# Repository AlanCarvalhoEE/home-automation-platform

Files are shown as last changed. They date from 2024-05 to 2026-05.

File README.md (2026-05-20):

# Home Automation Platform (HAP)

A modular, self-hosted home automation platform focused on reliability, local control, and secure remote access.

The system is designed around a Raspberry Pi server that centralizes application logic and device state, ESP8266-based IoT modules for field control, and a mobile
application as the primary user interface. Communication between components is event-driven and optimized for embedded and low-latency environments.

---

## System Architecture

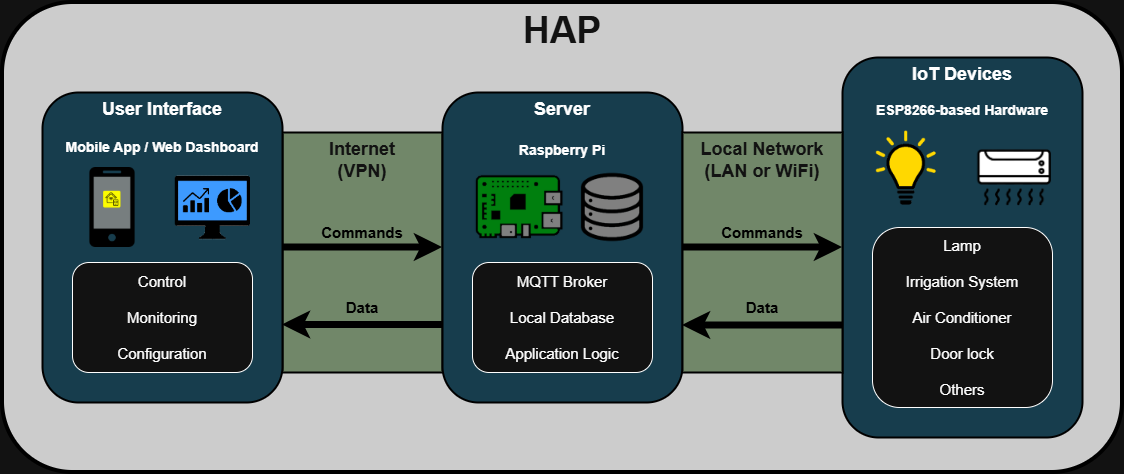
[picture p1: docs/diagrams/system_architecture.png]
System Architecture


The platform follows a layered architecture:

- **User Interface Layer**: Mobile and web-based interfaces for monitoring and
  control.
- **Application Layer**: Centralized logic running on a Raspberry Pi server.
- **Device Layer**: Custom ESP8266-based hardware modules controlling actuators
  and sensors.

Remote access is secured using a VPN, allowing the system to remain fully functional without relying on external cloud services.

---

## Components Overview

### Mobile App / Web Interface
- Provides real-time monitoring and control of devices
- Sends user commands to the server
- Displays device states and sensor data

### Server (Raspberry Pi)
- Central application logic
- Device state management
- Local database storage
- MQTT-based device communication
- REST API for configuration and user interfaces

### IoT Devices (ESP8266)
- Custom-designed hardware modules
- Event-driven communication using MQTT
- Designed as lightweight, replaceable nodes
- Examples:
  - On/Off relay modules
  - Sensor modules
  - Air conditioner control modules

---

## Repository Structure

```
hap/
├── docs/       # Documentation, diagrams, images
├── firmware/   # ESP8266 firmware for IoT modules
├── hardware/   # PCB designs, schematics, manufacturing files
├── mobile/     # Android application
├── server/     # Core server logic and services
└── README.md
```

---

## Technology Stack

### Embedded & Hardware
- ESP8266
- C / Arduino framework
- Custom PCB design

### Server
- Raspberry Pi
- Python
- MQTT
- SQLite
- TCP/IP networking

### Mobile
- Android (Java)
- Local and remote control support

### Communication & Security
- MQTT for device communication
- REST API for configuration and UI interaction
- VPN-based secure remote access
- Local-first architecture (no cloud dependency)

---

## Communication Model

- Devices publish state changes and sensor data via MQTT
- The server processes events and applies application logic
- Commands are sent back to devices via MQTT topics
- The mobile app interacts with the server through secure API calls

---

## System Setup Steps

- Install a lightweight Raspberry Pi OS:
  - Raspberry Pi OS Lite (recommended)
  - Enable SSH during installation
  - Configure a static local IP address

- Update the system:
```
sudo apt update
sudo apt upgrade -y
```

- Install and configure GIT:
```
sudo apt install git -y
```

- Clone the repository:
```
git clone https://github.com/AlanCarvalhoEE/hap.git
```

- Enter project folder:
```
cd hap
```

- Edit your credentials:
```
cp server/scripts/credentials_example.py server/scripts/credentials.py
nano server/scripts/credentials.py
```

- Run setup.sh:
```
cd setup
chmod +x setup.sh
./setup.sh
```
  - The script will install all the needed packages, dependencies and services.

- Configure Mosquitto:
```
sudo nano /etc/mosquitto/mosquitto.conf
```
  - Include to the end of the file:
  ```
  listener 1883
  allow_anonymous true
  ```

- Restart Mosquitto:
```
sudo systemctl restart mosquitto
```

- Connect to your ZeroTier network (must be previously created on web browser):
```
sudo zerotier-cli join <network_id>
```
  - After joining, the device must be allowed on the ZeroTier network dashboard.

- Reboot the Raspberry Pi:
```
sudo reboot now
```

---

## Current Status

- Core server architecture implemented
- Custom IoT ON-OFF module developed and tested
- Core Android application implemented
- Secure remote access functional

---

## Roadmap

Planned improvements:

- New custom IoT modules development
- Formal MQTT topic and message schema documentation
- Device auto-discovery and provisioning
- Improved fault tolerance and reconnection logic
- Automated testing for server-side logic
- Expanded mobile app features and UI refinement

---

## License

This project is currently intended for personal and educational use.
Licensing details may be defined in the future.

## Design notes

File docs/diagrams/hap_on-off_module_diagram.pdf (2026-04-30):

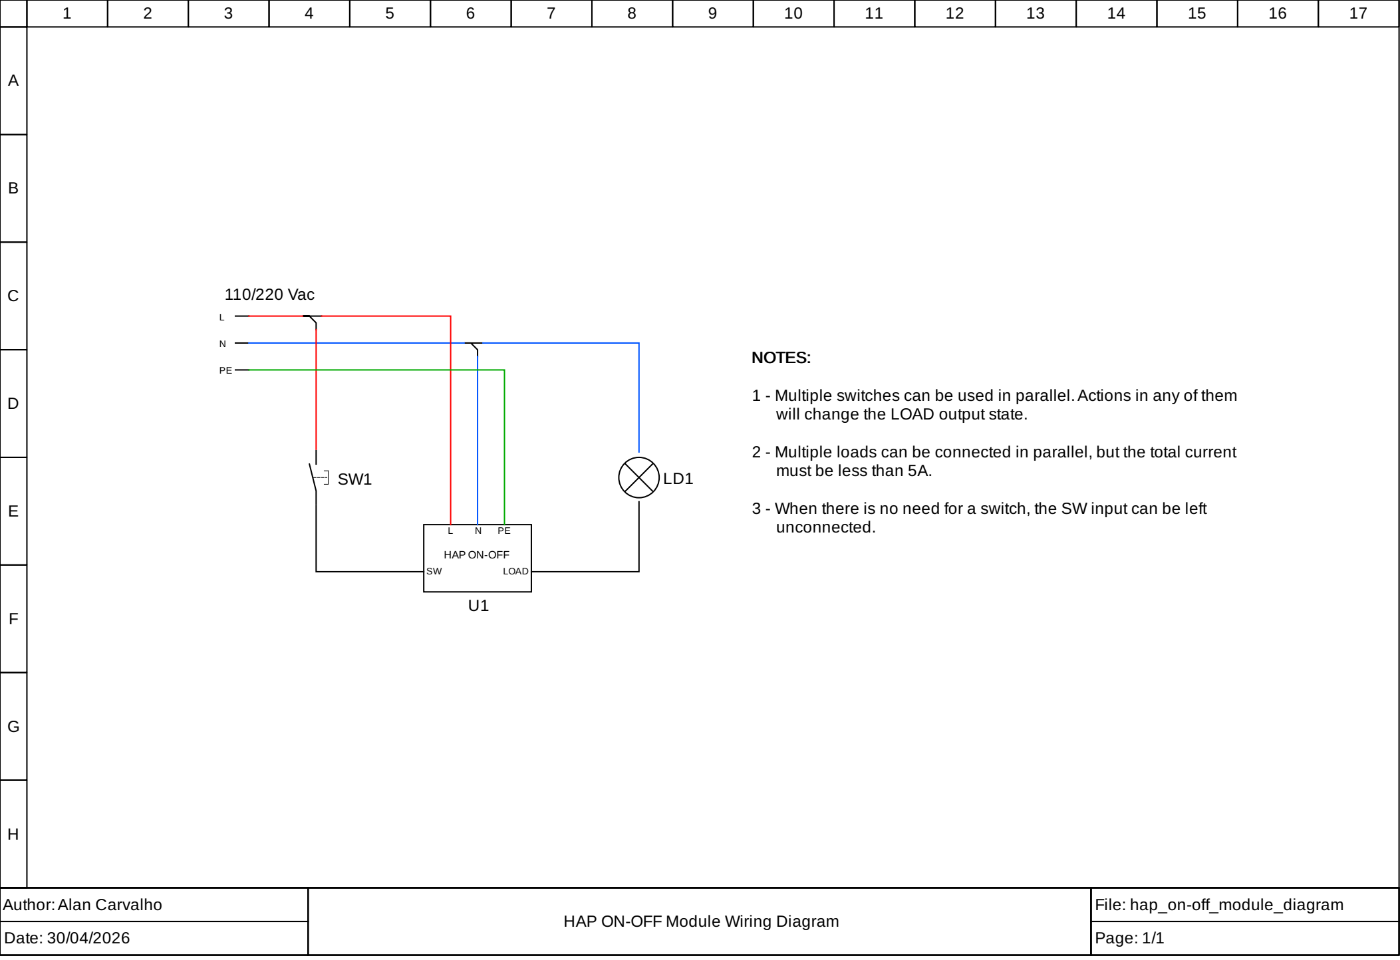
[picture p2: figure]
Author:Alan Carvalho; HAP ON-OFF Module Wiring Diagram; File: hap_on-off_module_diagram; Date: 30/04/2026; Page: 1/1; 110/220 Vac; NOTES:; will change the LOAD output state.; must be less than 5A.; unconnected.; LOAD; HAP ON-OFF

1 - Multiple switches can be used in parallel.Actions in any of them

2 - Multiple loads can be connected in parallel, but the total current

3 - When there is no need for a switch, the SW input can be left

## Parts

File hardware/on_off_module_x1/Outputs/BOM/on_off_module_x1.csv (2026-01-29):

Quantity | Value | Footprint | Designators
C1 | 0.1uF - 275V | CAP_THT_CERAMIC_X2_18x6x15 | 1
C2 | 100uF - 16V | CAP_SMD_ELEC_6.3x7.7 | 1
C3 | 10uF - 16V | CAP_SMD_TANTALUM_CASE-A | 1
C4 | 10uF - 6.3V | CAP_SMD_TANTALUM_CASE-A | 1
C5 | 0.1uF - 6.3V | CAP_SMD_CERAMIC_0603 | 1
C6 | 47nF - 350V | CAP_THT_CERAMIC_X2_13x5x11_P10 | 1
C7 | 100nF - 6 | 3V | CAP_SMD_CERAMIC_0603 | 1
D1 | LED | LED_SMD_0603 | 1
D2 | S1A | DIODE_SMD_SMA | 1
F1 | 0 | 25A - 250V | FUSEHOLDER_THT_5x20_CLIP | 1
J1 | CONN_TERMINAL-BLOCK_5P_P5.08 | CONN_TERMINAL-BLOCK_5P_P5.08 | 1
J2 | Conn_01x06_Socket | CONN_SOCKET-HEADER_1x06_V | 1
J3 | Conn_01x03_Socket | CONN_PIN-HEADER_1x03_V | 1
K1 | 12V 5A | RELAY_SPDT_FINDER_36.11 | 1
L1 | 600R | BEAD_SMD_1206 | 1
PS1 | HLK-PM12 - 3W | HILINK_HLK-PMxx | 1
Q1 | 2N7002H | SOT-23 | 1
R10 | R11 | 33k - 5% - 1/4W | RES_SMD_1206 | 2
R1 | R2 | R3 | R6 | R12 | 10k - 5% - 1/10W | RES_SMD_0603 | 5
R4 | 2k2 - 5% - 1/10W | RES_SMD_0603 | 1
R5 | 390R - 5% - 1/10W | RES_SMD_0603 | 1
R7 | 33k - 5% - 1/10W | RES_SMD_0603 | 1
R8 | 10k | LDR_5_V | 1
R9 | 470k - 5% - 1/4W | RES_SMD_1206 | 1
U1 | AMS1117-3.3 - 3.3W | SOT-223-3_TAB2 | 1
U2 | ESP-12E | MOD_ESP-12E | 1
U3 | PC817 | SMDIP-4_7.62 | 1
U4 | H11AA1 | SMDIP-6_7.62 | 1

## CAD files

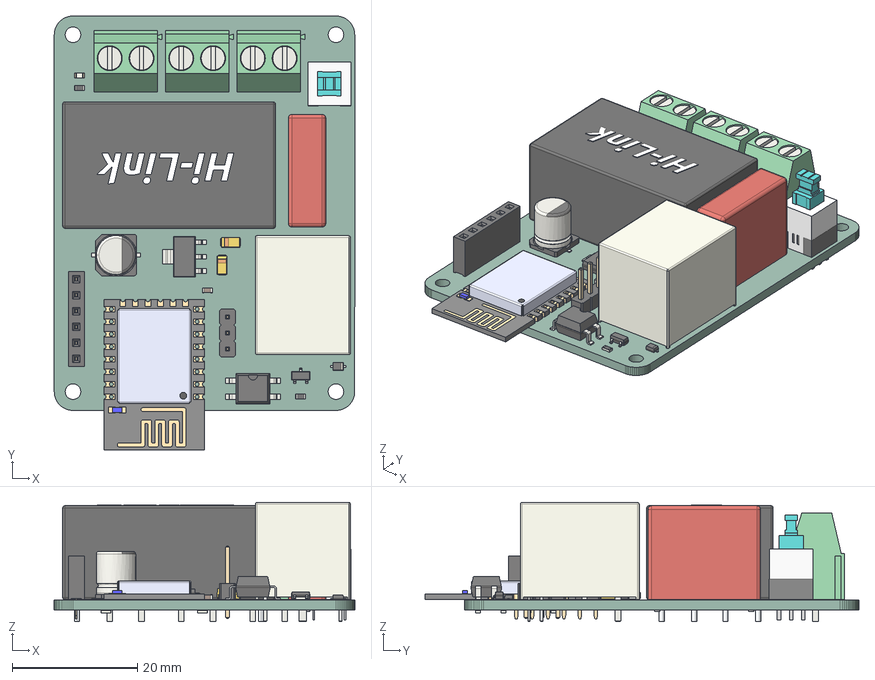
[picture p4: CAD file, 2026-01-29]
hardware/on_off_module_x1/ON-OFF Module X1 PCB.step
48.0 x 69.3 x 19.0 mm
on_off_module_x1 PCB

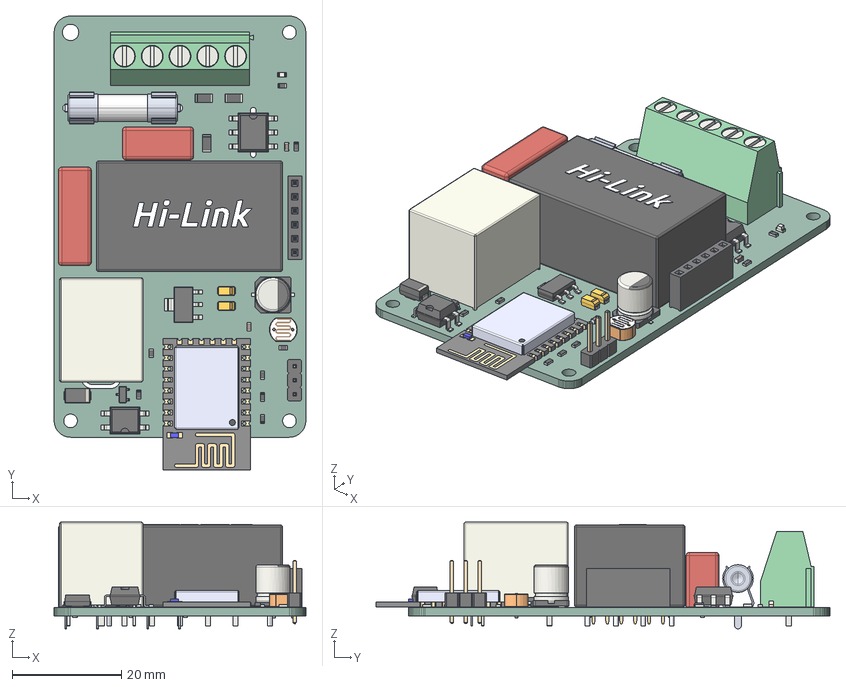
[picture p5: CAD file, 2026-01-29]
hardware/on_off_module_x1/Outputs/3D/on_off_module_x1.step
46.0 x 83.0 x 19.5 mm
on_off_module_x1 PCB

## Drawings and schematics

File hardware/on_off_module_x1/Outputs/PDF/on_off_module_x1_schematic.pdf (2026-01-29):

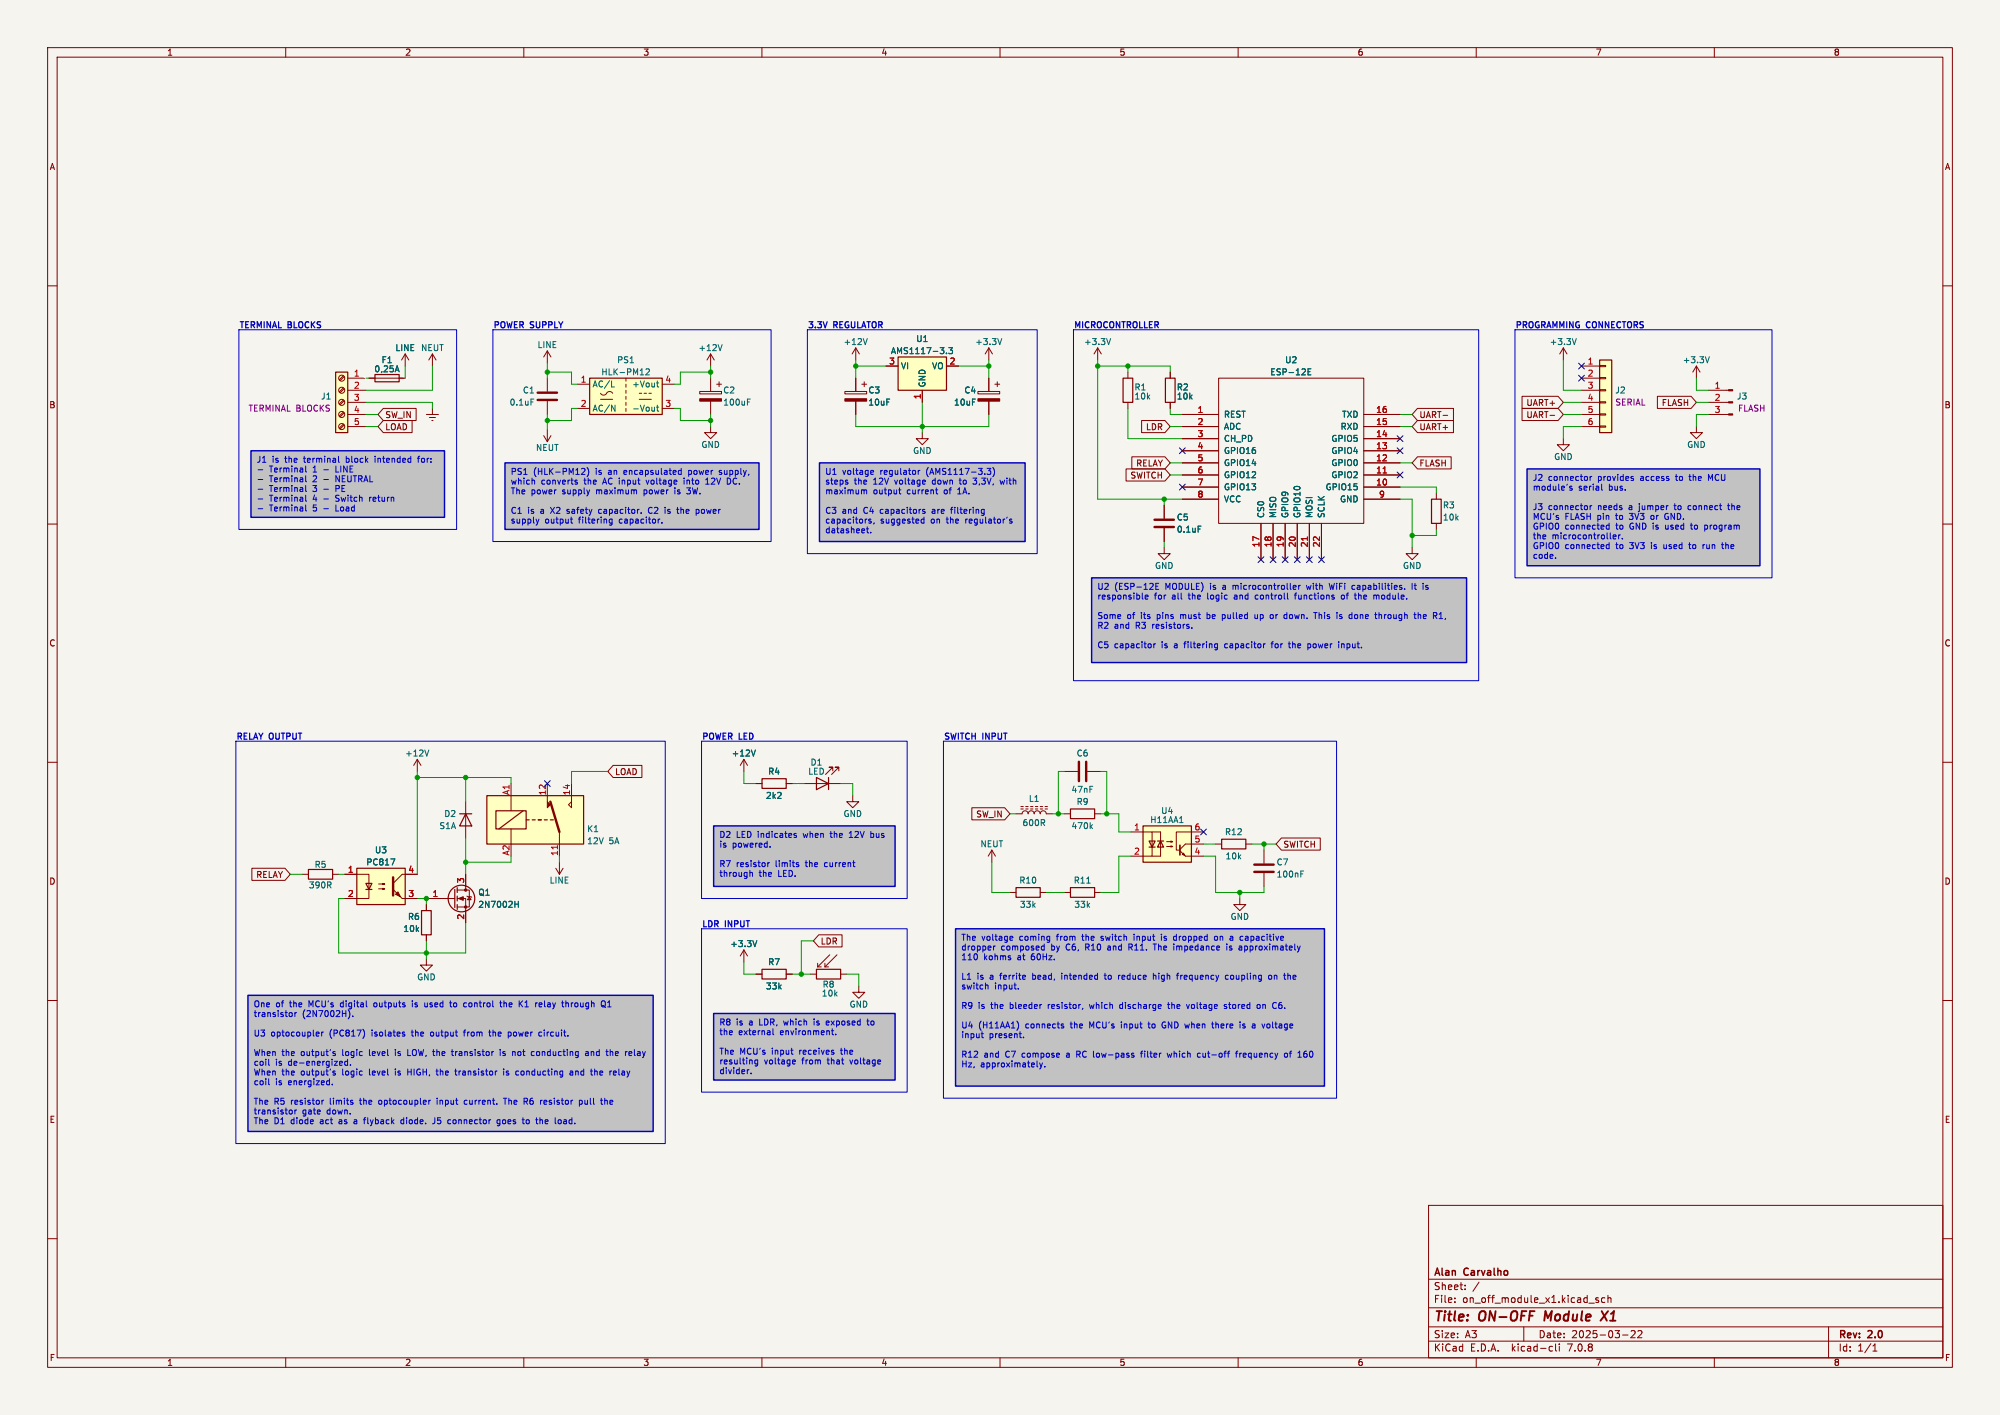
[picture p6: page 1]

File: on_off_module_x1.kicad_sch Sheet: / Alan Carvalho GND

Id: 1/1 Title: ON-OFF Module X1

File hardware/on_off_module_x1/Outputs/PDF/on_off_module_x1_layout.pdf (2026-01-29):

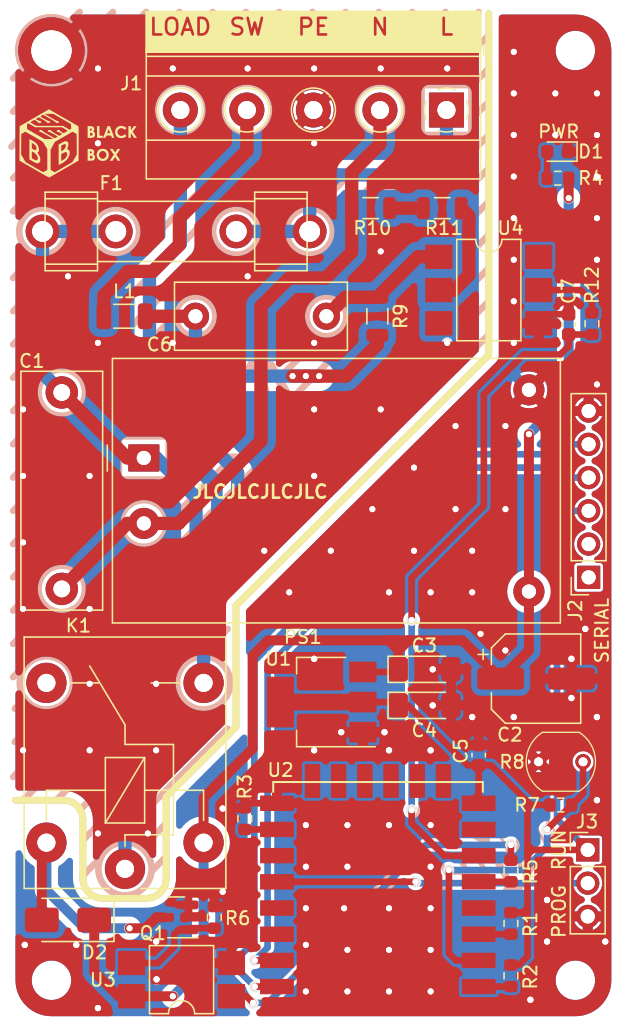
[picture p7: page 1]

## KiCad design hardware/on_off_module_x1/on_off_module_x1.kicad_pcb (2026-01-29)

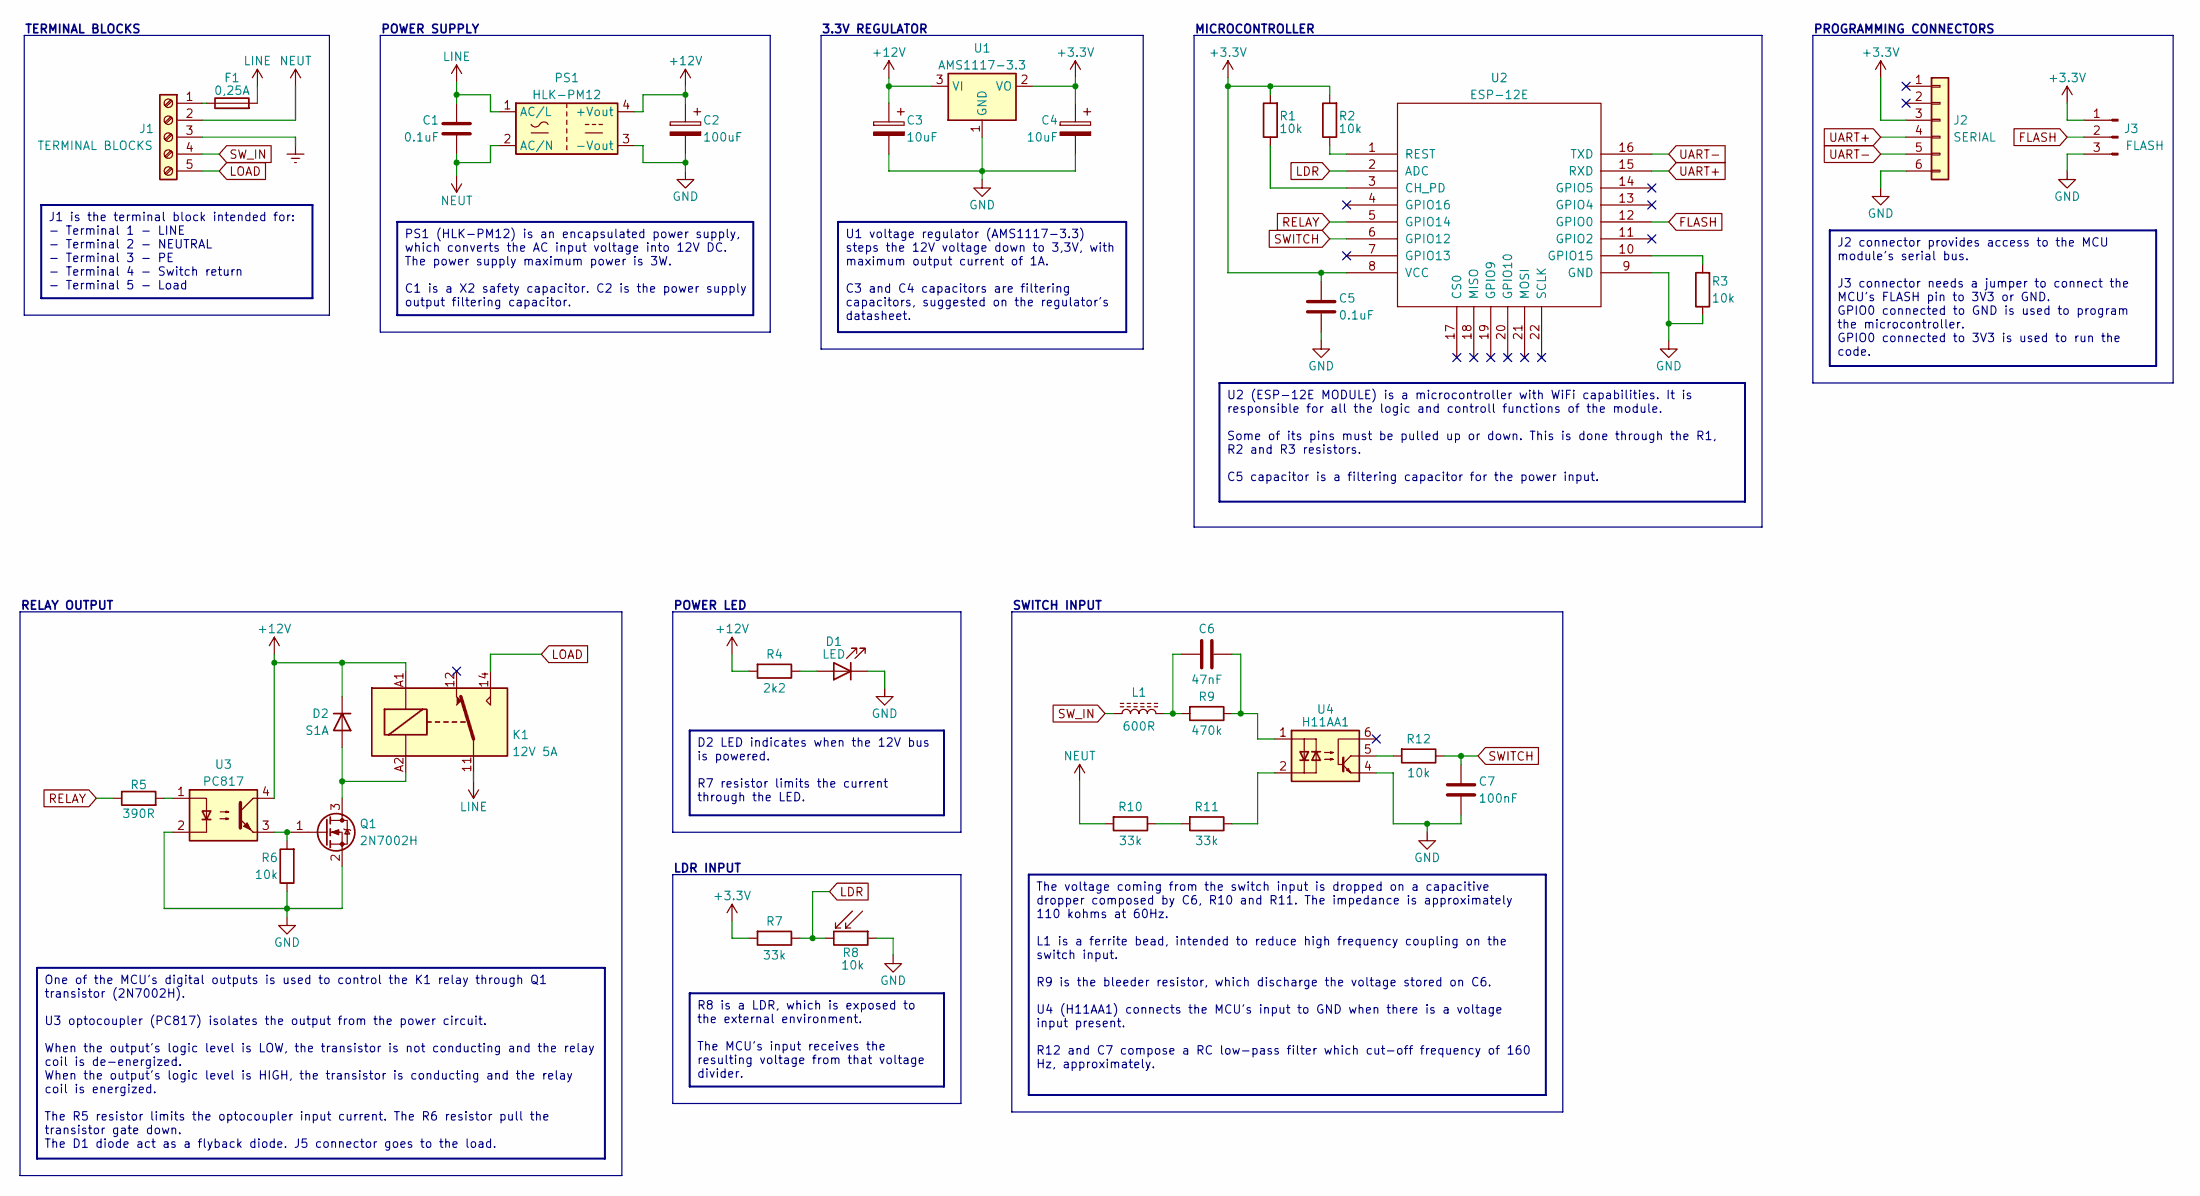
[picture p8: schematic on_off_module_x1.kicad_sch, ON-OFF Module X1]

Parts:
C1: 0.1uF; CAP_THT_CERAMIC_X2_18x6x15; Voltage 275V
C2: 100uF; CAP_SMD_ELEC_6.3x7.7; Voltage 16V
C3: 10uF; CAP_SMD_TANTALUM_CASE-A; Voltage 16V
C4: 10uF; CAP_SMD_TANTALUM_CASE-A; Voltage 6.3V
C5: 0.1uF; CAP_SMD_CERAMIC_0603; Voltage 6.3V
C6: 47nF; CAP_THT_CERAMIC_X2_13x5x11_P10; Voltage 350V
C7: 100nF; CAP_SMD_CERAMIC_0603; Voltage 6,3V
D1: LED; LED_SMD_0603
D2: S1A; DIODE_SMD_SMA
F1: 0,25A; FUSEHOLDER_THT_5x20_CLIP; Voltage 250V
J1: CONN_TERMINAL-BLOCK_5P_P5.08
J2: Conn_01x06_Socket; CONN_SOCKET-HEADER_1x06_V
J3: Conn_01x03_Socket; CONN_PIN-HEADER_1x03_V
K1: 12V 5A; RELAY_SPDT_FINDER_36.11
L1: 600R; BEAD_SMD_1206
PS1: HLK-PM12; HILINK_HLK-PMxx
Q1: 2N7002H; SOT-23
R1, R2, R3, R6, R12: 10k; RES_SMD_0603; Tolerance 5%
R4: 2k2; RES_SMD_0603; Tolerance 5%
R5: 390R; RES_SMD_0603; Tolerance 5%
R7: 33k; RES_SMD_0603; Tolerance 5%
R8: 10k; LDR_5_V
R9: 470k; RES_SMD_1206; Tolerance 5%
R10, R11: 33k; RES_SMD_1206; Tolerance 5%
U1: AMS1117-3.3; SOT-223-3_TAB2
U2: ESP-12E; MOD_ESP-12E
U3: PC817; SMDIP-4_7.62
U4: H11AA1; SMDIP-6_7.62

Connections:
+3.3V: C4.1, C5.2, J2.3, J3.1, R1.1, R2.1, R7.1, U1.2 (VO), U2.8 (VCC)
+12V: C2.1, C3.1, D2.1 (K), K1.A1, PS1.4 (+Vout), R4.1, U1.3 (VI), U3.4
Earth: J1.3
FLASH: J3.2, U2.12 (GPIO0)
GND: C2.2, C3.2, C4.2, C5.1, C7.2, D1.1 (K), J2.6, J3.3, PS1.3 (-Vout), Q1.2 (S), R3.2, R6.2, R8.1, U1.1 (GND), U2.9 (GND), U3.2, U4.4
LDR: R7.2, R8.2, U2.2 (ADC)
LINE: C1.1, F1.2, K1.11, PS1.1 (AC/L)
LOAD: J1.5, K1.14
NEUT: C1.2, J1.2, PS1.2 (AC/N), R10.1
unnamed: C6.1, L1.2, R9.1
unnamed: C6.2, R9.2, U4.1
unnamed: D1.2 (A), R4.2
unnamed: D2.2 (A), K1.A2, Q1.3 (D)
unnamed: F1.1, J1.1
unnamed: Q1.1 (G), R6.1, U3.3
unnamed: R5.1, U3.1
unnamed: R10.2, R11.1
unnamed: R11.2, U4.2
unnamed: R12.1, U4.5
unnamed: R1.2, U2.3 (CH_PD)
unnamed: R3.1, U2.10 (GPIO15)
unnamed: R2.2, U2.1 (REST)
RELAY: R5.2, U2.5 (GPIO14)
SWITCH: C7.1, R12.2, U2.6 (GPIO12)
SW_IN: J1.4, L1.1
UART+: J2.4, U2.15 (RXD)
UART-: J2.5, U2.16 (TXD)

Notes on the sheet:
PS1 (HLK-PM12) is an encapsulated power supply, which converts the AC input voltage into 12V DC. The power supply maximum power is 3W. C1 is a X2 safety capacitor. C2 is the power supply output filtering capacitor.
R8 is a LDR, which is exposed to the external environment. The MCU's input receives the resulting voltage from that voltage divider.
One of the MCU's digital outputs is used to control the K1 relay through Q1 transistor (2N7002H). U3 optocoupler (PC817) isolates the output from the power circuit. When the output's logic level is LOW, the transistor is not conducting and the relay coil is de-energized. When the output's logic lev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
J2 connector provides access to the MCU module's serial bus. J3 connector needs a jumper to connect the MCU's FLASH pin to 3V3 or GND. GPIO0 connected to GND is used to program the microcontroller. GPIO0 connected to 3V3 is used to run the code.
D2 LED indicates when the 12V bus is powered. R7 resistor limits the current through the LED.
U2 (ESP-12E MODULE) is a microcontroller with WiFi capabilities. It is responsible for all the logic and controll functions of the module. Some of its pins must be pulled up or down. This is done through the R1, R2 and R3 resistors. C5 capacitor is a filtering capacitor for the power input.
U1 voltage regulator (AMS1117-3.3) steps the 12V voltage down to 3,3V, with maximum output current of 1A. C3 and C4 capacitors are filtering capacitors, suggested on the regulator's datasheet.
J1 is the terminal block intended for: - Terminal 1 - LINE - Terminal 2 - NEUTRAL - Terminal 3 - PE - Terminal 4 - Switch return - Terminal 5 - Load
The voltage coming from the switch input is dropped on a capacitive dropper composed by C6, R10 and R11. The impedance is approximately 110 kohms at 60Hz. L1 is a ferrite bead, intended to reduce high frequency coupling on the switch input. R9 is the bleeder resistor, which discharge the voltage st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
PROGRAMMING CONNECTORS
RELAY OUTPUT
POWER LED
POWER SUPPLY
LDR INPUT
TERMINAL BLOCKS
SWITCH INPUT
MICROCONTROLLER
3.3V REGULATOR

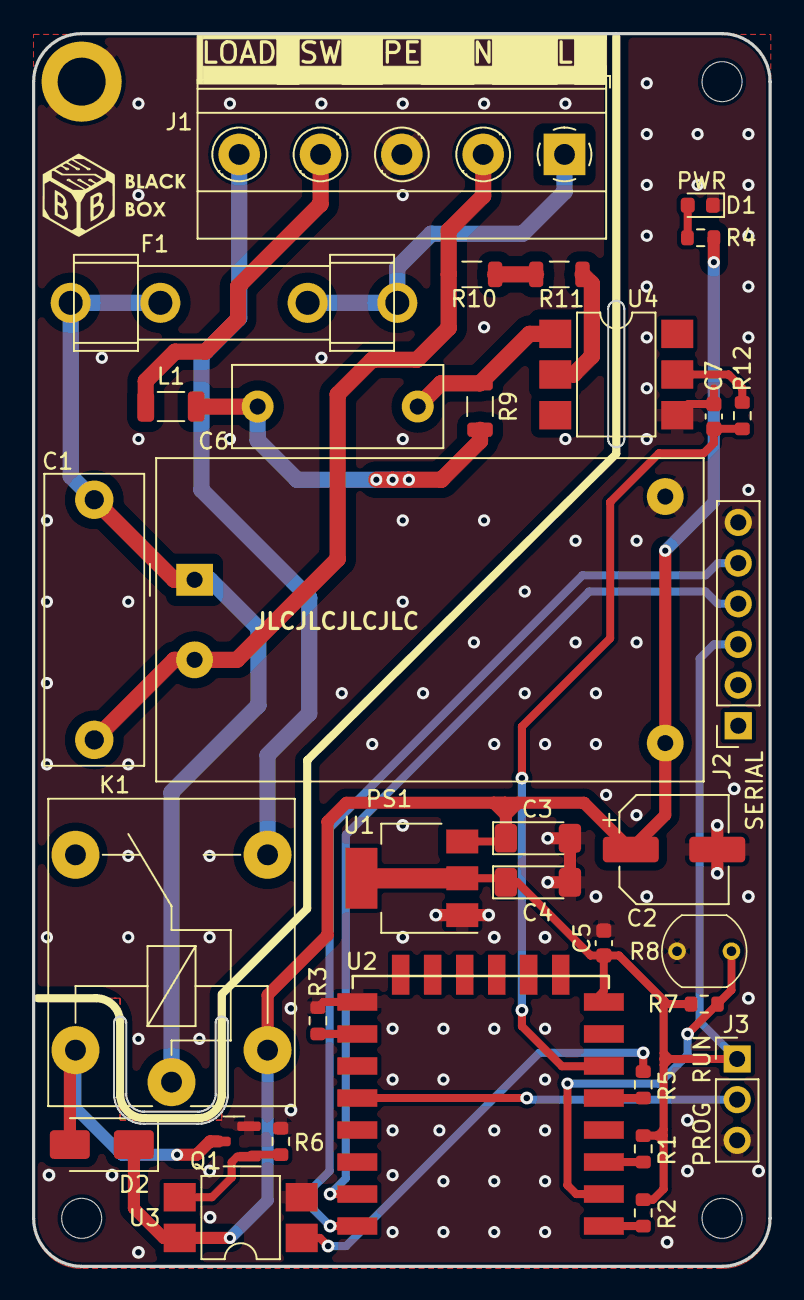
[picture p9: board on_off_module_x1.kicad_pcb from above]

Board: 2 copper layers, 46.0 x 77.0 mm, 33 parts (0 on the bottom side), 26 nets.

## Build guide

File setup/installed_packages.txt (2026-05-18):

git
mosquitto
mosquitto-clients
python-is-python3
python3-pip
python3-rpi.gpio
sqlite3
network-manager
iptables-persistent
rsync
curl
nano
tree

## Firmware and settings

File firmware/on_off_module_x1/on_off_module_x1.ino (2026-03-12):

// Project - HAP - Home Automation Platform 
// Code - ON-OFF module X1
// Author - Alan Carvalho
// Date - 05/03/2026

// Libraries
#include <ESP8266WiFi.h>
#include <PubSubClient.h>
#include <EEPROM.h>
#include <ArduinoJson.h>
#include <ESP8266httpUpdate.h>
#include "credentials.h"

// Firmware Information
#define FW_TAG "on-off"
#define FW_VERSION "1.0.1"

// Device Parameters
#define TYPE "lamp"
#define HAP_TOPIC "hap"
#define DEVICE_TOPIC "device"
#define SET_STATE_TOPIC "set_state"
#define GET_STATE_TOPIC "get_state"
#define STATUS_TOPIC "status"
#define ENABLE_LDR_TOPIC "enable_ldr"
#define ADJUST_LDR_TOPIC "adjust_ldr"
#define DISCOVERY_TOPIC "discovery"
#define UPDATE_TOPIC "update"

// Pins
#define SWITCH_PIN 12
#define RELAY_PIN 14
#define LDR_PIN A0

// WiFi and MQTT clients
WiFiClient tcpClient;
PubSubClient mqttClient(tcpClient);

// Variables
bool loadOn = false;                          // Load state (ON = true, OFF = false)
bool ldrEnabled = false;                      // Defines whether the LDR is enabled or not
bool wifiConnected = false;                   // WiFi connection status (Connected = true, Disconnected = false)
unsigned int ldrReading = 0;                  // LDR reading value (0 to 1023)
unsigned int ldrThreshold = 600;              // Threshold to turn the output ON or OFF based on LDR input 
const unsigned int ldrHisteresis = 50;        // Histeresis to avoid output flickering

// Timing
unsigned long lastWifiCheck = 0;              // Last time the WiFi connection was checked (ms)
const long wifiCheckInterval = 5000;          // Interval to check the WiFi connection (ms)
unsigned long lastBrokerCheck = 0;            // Last time the broker connection was checked (ms)
const long brokerCheckInterval = 5000;        // Interval to check the broker connection (ms)
unsigned long lastDiscoveryPublish = 0;       // Last time the device has published to discovery topic (ms)
const long discoveryPublishInterval = 5000;   // Interval to publish to discovery topic (ms)
unsigned long lastReportPrint = 0;            // Last time the report was printed (ms)
const long reportPrintInterval = 500;         // Interval to print the report (ms)
unsigned long lastSwitchChange = 0;           // Last time the switch state has changed (ms)
const long debounceInterval = 500;            // Interval to debounce the switch state changing (ms)
unsigned long lastLdrCheck = 0;               // Last time the LDR input was checked (ms)
const long ldrCheckInterval = 10000;          // Interval to check the LDR input (ms)

// MQTT Strings
String deviceId;                              // The device's ID
String setStateTopic;                         // Topic for setting the module state
String getStateTopic;                         // Topic for retrieving the module state
String statusTopic;                           // Topic for online/offline status
String enableLdrTopic;                        // Topic for enabling and disabling the LDR
String adjustLdrTopic;                        // Topic for adjusting the LDR threshold
String discoveryTopic;                        // Topic for device discovery capability
String updateTopic;                           // Topic for firmware update over HTTP

// OTA Callbacks
void update_started() {
  Serial.println("OTA: Started");
}
void update_finished() {
  Serial.println("OTA: Finished");
}
void update_progress(int cur, int total) {
  Serial.printf("OTA: %d / %d bytes\n", cur, total);
}
void update_error(int err) {
  Serial.printf("OTA: Error %d\n", err);
}

// Initial Setup
void setup() {

  // Start the serial port
  Serial.begin(115200);
  delay(3000);

  // Configure the GPIO
  pinMode(SWITCH_PIN, INPUT_PULLUP);
  pinMode(RELAY_PIN, OUTPUT);
  pinMode(LDR_PIN, INPUT);

  // Starts with the load turned OFF
  digitalWrite(RELAY_PIN, loadOn);

  // Start the EEPROM with 16 bytes
  EEPROM.begin(16);

  // Update the LDR variables from EEPROM
  EEPROM.get(2, ldrEnabled);
  EEPROM.get(0, ldrThreshold);
  if (ldrThreshold == 0xFFFF || ldrThreshold > 1023) ldrThreshold = 600;

  //Configure the WiFi
  WiFi.mode(WIFI_STA);

  // Configure the MQTT client
  mqttClient.setServer(brokerIP, brokerPort);
  mqttClient.setCallback(callback);

  generateDeviceId();   // Generates the device ID
  buildTopics();        // Builds all the relevant topics
}

// Loop
void loop() {
  
  checkWifiConnection();      // Check the WiFi connection status
  checkBrokerConnection();    // Check the MQTT connection status

  if (mqttClient.connected()) mqttClient.loop();  // Whatch MQTT topics

  if (!ldrEnabled) checkSwitch();   // Check switch changes
  if (ldrEnabled) checkLDR();       // Check LDR changes

  publishDiscovery(); // Publish to discovery topic
  printReport();      // Print relevant data
}

// Function to generate the device ID
void generateDeviceId() {

  deviceId = WiFi.macAddress();
  deviceId.replace(":", "");
  deviceId.toLowerCase();
}

// Function to build the topics
void buildTopics() {

  String base = String(HAP_TOPIC) + "/" + DEVICE_TOPIC + "/" + deviceId + "/";

  setStateTopic = base + SET_STATE_TOPIC;
  getStateTopic = base + GET_STATE_TOPIC;
  statusTopic = base + STATUS_TOPIC;
  enableLdrTopic = base + ENABLE_LDR_TOPIC;
  adjustLdrTopic = base + ADJUST_LDR_TOPIC;
  updateTopic = base + UPDATE_TOPIC;

  discoveryTopic = String(HAP_TOPIC) + "/" + DISCOVERY_TOPIC + "/" + deviceId;
}

// Function to setup WiFi
void checkWifiConnection() {

  if ((millis() - lastWifiCheck) > wifiCheckInterval) {

    if (WiFi.status() == WL_CONNECTED) {
      wifiConnected = true;
    } else {
      WiFi.begin(ssid, password);
      wifiConnected = false;
    }

    lastWifiCheck = millis();
  }
}

// Function to setup the broker connection
void checkBrokerConnection() {

  if (wifiConnected && ((millis() - lastBrokerCheck) > brokerCheckInterval)) {

    if (!mqttClient.connected()) {

      if (mqttClient.connect(deviceId.c_str(), statusTopic.c_str(), 1, true, "OFFLINE")) {

        mqttClient.subscribe(setStateTopic.c_str());
        mqttClient.subscribe(enableLdrTopic.c_str());
        mqttClient.subscribe(adjustLdrTopic.c_str());
        mqttClient.subscribe(updateTopic.c_str());

        mqttClient.publish(statusTopic.c_str(), "ONLINE", true);

        publishDiscovery();
        publishState();
      }
    }

    lastBrokerCheck = millis();
  }
}

// Function to handle received MQTT commands
void callback(char* topic, byte* payload, unsigned int length) {

  payload[length] = '\0';
  String message = String((char*)payload);

  if (strcmp(topic, updateTopic.c_str()) == 0) {

    StaticJsonDocument<128> doc;

    if (!deserializeJson(doc, message)) {
      String version = doc["version"];
      performOTA(version);
    }
    return;
  }

  if (strcmp(topic, setStateTopic.c_str()) == 0) {
    loadOn = (message == "ON");
    digitalWrite(RELAY_PIN, loadOn);
  }

  if (strcmp(topic, enableLdrTopic.c_str()) == 0) {
    ldrEnabled = (message == "ENABLE");
    EEPROM.put(2, ldrEnabled);
    EEPROM.commit();
  }

  if (strcmp(topic, adjustLdrTopic.c_str()) == 0) {
    ldrThreshold = message.toInt();
    EEPROM.put(0, ldrThreshold);
    EEPROM.commit();
  }

  publishState();
}

// Function to perform firmware update
void performOTA(String version) {

  if (version == FW_VERSION) {
    Serial.println("OTA: Already running this version.");
    return;
  }

  if (WiFi.status() != WL_CONNECTED) return;

  mqttClient.publish(statusTopic.c_str(), "UPDATING", true);
  delay(200);
  mqttClient.disconnect();
  delay(500);

  char url[128];
  snprintf(url, sizeof(url),
         "http://%s:%d/firmware/%s_v%s.bin",
         FW_SERVER_IP,
         FW_SERVER_PORT,
         FW_TAG,
         version.c_str());

  ESPhttpUpdate.setLedPin(LED_BUILTIN, LOW);
  ESPhttpUpdate.setClientTimeout(30000);

  ESPhttpUpdate.onStart(update_started);
  ESPhttpUpdate.onEnd(update_finished);
  ESPhttpUpdate.onProgress(update_progress);
  ESPhttpUpdate.onError(update_error);

  WiFiClient client;
  t_httpUpdate_return ret = ESPhttpUpdate.update(client, url);

  switch (ret) {

    case HTTP_UPDATE_FAILED:
      Serial.printf("OTA Failed (%d): %s\n",
        ESPhttpUpdate.getLastError(),
        ESPhttpUpdate.getLastErrorString().c_str());
      break;

    case HTTP_UPDATE_NO_UPDATES:
      Serial.println("No Update Available");
      break;

    case HTTP_UPDATE_OK:
      Serial.println("Update Successful");
      break;
  }
}

// Function to check the switch state
void checkSwitch() {

  if (digitalRead(SWITCH_PIN) == LOW &&
      ((millis() - lastSwitchChange) > debounceInterval)) {

    loadOn = !loadOn;
    digitalWrite(RELAY_PIN, loadOn);
    publishState();
    lastSwitchChange = millis();
  }
}

// Function to check the LDR state
void checkLDR() {

  if ((millis() - lastLdrCheck) > ldrCheckInterval) {

    ldrReading = analogRead(LDR_PIN);

    if (!loadOn && (ldrReading > (ldrThreshold + ldrHisteresis))) {
      loadOn = true;
      digitalWrite(RELAY_PIN, HIGH);
    }
    else if (loadOn && (ldrReading < (ldrThreshold - ldrHisteresis))) {
      loadOn = false;
      digitalWrite(RELAY_PIN, LOW);
    }

    publishState();
    lastLdrCheck = millis();
  }
}

// Function to publish device state
void publishState() {

  StaticJsonDocument<192> doc;

  doc["fw_version"] = FW_VERSION;
  doc["load_status"] = loadOn ? "ON" : "OFF";
  doc["ldr_status"] = ldrEnabled ? "ENABLED" : "DISABLED";
  doc["ldr_threshold"] = ldrThreshold;
  doc["ldr_value"] = ldrReading;

  char buffer[192];
  serializeJson(doc, buffer);

  mqttClient.publish(getStateTopic.c_str(), buffer, true);
}

// Function to publish to the discovery topic
void publishDiscovery() {

  if ((millis() - lastDiscoveryPublish) > discoveryPublishInterval) {
    
    StaticJsonDocument<96> doc;

    doc["id"] = deviceId;
    doc["type"] = TYPE;

    char buffer[96];
    serializeJson(doc, buffer);

    mqttClient.publish(discoveryTopic.c_str(), buffer, false);

    lastDiscoveryPublish = millis();
  }
}

// Function to print relevant variables
void printReport() {

  if ((millis() - lastReportPrint) > reportPrintInterval) {

    Serial.print("Firmware Tag: ");
    Serial.println(FW_TAG);

    Serial.print("Firmware Version: ");
    Serial.println(FW_VERSION);

    Serial.print("WiFi Status: "); 
    if (WiFi.status() == WL_CONNECTED) {
      Serial.print("Connected with IP address ");
      Serial.println(WiFi.localIP());
    }
    else (Serial.println("Disconnected"));

    Serial.print("MQTT Status: ");
    if (mqttClient.connected()) Serial.println("Connected");
    else (Serial.println("Disconnected"));

    Serial.print("Switch Status: ");
    if (digitalRead(SWITCH_PIN) == LOW) Serial.println("Pressed");
    else Serial.println("Not pressed");

    Serial.print("LDR Status: ");
    if (ldrEnabled) Serial.println("Enabled");
    else Serial.println("Disabled");

    Serial.print("Light Threshold: ");
    Serial.println(ldrThreshold);

    Serial.print("Light Intensity: ");
    Serial.println(ldrReading);

    Serial.print("Load Status: ");
    if (loadOn) Serial.println("ON");
    else Serial.println("OFF");

    Serial.println("");
    lastReportPrint = millis();
  }
}

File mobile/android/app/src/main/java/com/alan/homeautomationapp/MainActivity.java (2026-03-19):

package com.alan.homeautomationapp;

import android.annotation.SuppressLint;
import android.content.Intent;
import android.os.Bundle;
import android.view.View;
import android.widget.AdapterView;
import android.widget.ImageButton;
import android.widget.LinearLayout;
import android.widget.Spinner;

import androidx.annotation.NonNull;
import androidx.appcompat.app.ActionBar;
import androidx.appcompat.app.AppCompatActivity;

import java.util.Objects;

// Class responsible for running the main activity (main screen)
public class MainActivity extends AppCompatActivity {

    private DatabaseManager databaseManager;                // DatabaseManager instance
    private DeviceManager.DeviceUpdateListener listener;    // DeviceManager listener

    @SuppressLint({"ClickableViewAccessibility", "UseCompatLoadingForDrawables"})
    @Override
    protected void onCreate(Bundle savedInstanceState) {
        super.onCreate(savedInstanceState);

        // Load the layout
        setContentView(R.layout.activity_main);

        // Initialize database instance
        databaseManager = DatabaseManager.getInstance(this);
        databaseManager.getWritableDatabase();

        // Configure the action bar
        Objects.requireNonNull(this.getSupportActionBar()).setDisplayOptions(ActionBar.DISPLAY_SHOW_CUSTOM);
        getSupportActionBar().setDisplayShowCustomEnabled(true);
        getSupportActionBar().setCustomView(R.layout.custom_action_bar);
        View actionBarView = getSupportActionBar().getCustomView();
        androidx.appcompat.widget.Toolbar toolbar = (androidx.appcompat.widget.Toolbar) actionBarView.getParent();
        toolbar.setContentInsetsAbsolute(0,0);

        // Component references
        ImageButton configurationImageButton = actionBarView.findViewById(R.id.configurationImageButton);
        ImageButton languageImageButton = actionBarView.findViewById(R.id.languageImageButton);
        Spinner roomSpinner = findViewById(R.id.roomSpinner);
        LinearLayout roomDevicesLayout = findViewById(R.id.roomDevicesLayout);

        // Configure the language button
        String currentLanguage = LanguageManager.getLanguage();
        switch (currentLanguage) {
            case "pt": languageImageButton.setImageDrawable(getDrawable(R.drawable.portuguese_image));
                break;
            default: languageImageButton.setImageDrawable(getDrawable(R.drawable.english_image));
        }

        // Update rooms on the spinner
        MainScreenRenderer.updateRooms(this, roomSpinner);
        if (roomSpinner.getAdapter().getCount() > 0) {
            String roomName = roomSpinner.getSelectedItem().toString();
            MainScreenRenderer.updateDevices(this, roomName, roomDevicesLayout);
        }

        // Configuration button listener
        configurationImageButton.setOnClickListener(v -> {
            Intent intent = new Intent(MainActivity.this, ConfigurationActivity.class);
            startActivity(intent);
        });

        // Language button listener
        languageImageButton.setOnClickListener(v -> {
            DialogManager.openLanguageSelectionDialog(this, currentLanguage);
        });

        // Room selection spinner listener
        roomSpinner.setOnItemSelectedListener(new AdapterView.OnItemSelectedListener() {
            @Override
            public void onItemSelected(AdapterView<?> parentView, View selectedItemView, int position, long id) {
                MainScreenRenderer.updateDevices(MainActivity.this, roomSpinner.getSelectedItem().toString(), roomDevicesLayout);
            }
            @Override
            public void onNothingSelected(AdapterView<?> parentView) {}
        });

        // Listener to update the screen when there is an update on devices
        listener = device ->
                runOnUiThread(() ->
                        MainScreenRenderer.updateDevices(
                                MainActivity.this,
                                roomSpinner.getSelectedItem().toString(),
                                roomDevicesLayout)
        );
        DeviceManager.getInstance(this).addListener(listener);
    }

    @Override
    protected void onResume() {
        super.onResume();

        Spinner roomSpinner = findViewById(R.id.roomSpinner);
        LinearLayout roomDevicesLayout = findViewById(R.id.roomDevicesLayout);

        MainScreenRenderer.updateRooms(this, roomSpinner);
        if (roomSpinner.getAdapter().getCount() > 0) {
            MainScreenRenderer.updateDevices(this, roomSpinner.getSelectedItem().toString(), roomDevicesLayout);
        }
    }

    @Override
    protected void onSaveInstanceState(@NonNull Bundle savedInstanceState) {
        super.onSaveInstanceState(savedInstanceState);
    }

    @Override
    protected void onRestoreInstanceState(@NonNull Bundle savedInstanceState) {
        super.onRestoreInstanceState(savedInstanceState);
    }

    @Override
    protected void onStop() {
        super.onStop();
    }

    @Override
    protected void onDestroy() {
        super.onDestroy();
        DeviceManager.getInstance(this).removeListener(listener);
    }
}

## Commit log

2023-09-26 Location and device input dialogs created
2023-09-28 New device database input implemented
2023-09-29 Device designator numbering fixed
2023-09-29 Rooms and devices update implemented in the configuration window
2023-10-01 Relays control adjusted
2023-10-10 Removed the main database from the Android device
2023-10-17 Created components for some devices
2023-10-17 Togglebutton listener for ON/OFF devices implemented
2023-10-17 Air conditioner temperature control implemented
2024-01-18 Lamp module PCB schematic created
    [lamp_module.kicad_pcb, lamp_module.kicad_sch]
2024-01-20 Lamp module PCB V1.0 finished
    [lamp_module.kicad_pcb, lamp_module.kicad_sch]
2024-02-21 Lamp module 3D model finished
    [Lamp Module PCB.SLDPRT, Lamp module X1.SLDASM, Light switch.SLDPRT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]
2024-02-21 gerber files generated
    [lamp_module-B_Cu.gbl, lamp_module-B_Mask.gbs, lamp_module-B_Paste.gbp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]
2024-05-02 PCB simplified and improved
    [lamp_module.kicad_pcb, lamp_module.kicad_sch]
2024-05-02 Database update bug solved
    [MainActivity.java]
2024-05-06 Screen update implemented on adding room or device
2024-05-06 Device IP address included on database
2024-05-07 Gerber and image files updated
    [Lamp Module PCB.SLDPRT, Lamp module X1.SLDASM, Light switch.SLDPRT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]
2024-05-08 Switch feedback implemented
    [lamp_module_x1-B_Cu.gbl, lamp_module_x1-B_Mask.gbs, lamp_module_x1-B_Paste.gbp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]
2024-05-09 Lamp module X1 PCB finished
    [lamp_module_x1-B_Cu.gbl, lamp_module_x1-B_Mask.gbs, lamp_module_x1-B_Paste.gbp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]
2024-05-09 Fabrication files updated
    [lamp_module_x1-B_Cu.gbl, lamp_module_x1-B_Mask.gbs, lamp_module_x1-B_Paste.gbp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]
2024-05-10 PCB fabrication files updated
    [Lamp Module PCB.SLDPRT, Lamp module X1.SLDASM, Light switch.SLDPRT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]
2024-05-13 Database device deletion implemented
2024-05-13 Devices deletion implemented
2024-05-15 Camera streaming implemented
2024-05-28 Switch debounce implemented
2024-06-07 3D assembly updated
    [Lamp Module X2 PCB.SLDPRT, Lamp module X1.SLDASM, Light switch.SLDPRT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]
2024-06-08 Relay pin shanged
2024-06-13 Lamp control module assembly improved
    [Button mount.SLDPRT, Button mount.STL, Button.SLDPRT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]
2024-06-13 Changed switch reading logic
2024-06-17 Lamp control assembly finished
    [Button mount.SLDPRT, Button mount.STL, Button.SLDPRT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]
2024-06-20 Sensor module schematic created
    [sensor_module_x1.kicad_pcb, sensor_module_x1.kicad_sch]
2024-06-22 Sensor module PCB layout started
    [sensor_module_x1.kicad_pcb, sensor_module_x1.kicad_sch]
2024-06-27 Sensor module PCB layout finished
    [sensor_module.kicad_pcb, sensor_module.kicad_sch, sensor_module_x1.kicad_pcb]
2025-03-27 ON-OFF module hardware updated to V2
    [on_off_module_x1-B_Courtyard.gbr, on_off_module_x1-B_Cu.gbl, on_off_module_x1-B_Fab.gbr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]
2025-03-28 ON-OFF module X1 3D model updated
    [Junction box cover.SLDPRT, Junction box mount.SLDPRT, Junction box.SLDPRT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]
2026-01-29 General files structure refactoring
    [Junction box cover.SLDPRT, Junction box mount.SLDPRT, Junction box.SLDPRT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]
2026-01-29 Organize PCB project and firmware under hardware/and firmware/
    [Button mount.SLDPRT, Button mount.STL, Button.SLDPRT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]
2026-01-29 KiCad backup and cache files removed
2026-02-07 Device auto-discovery implemented on device's firmware.
2026-02-18 Implemented device auto-discovery on Android APP.
2026-02-20 Implemented new device/room manipulation methods
2026-03-04 Refactored rooms and devices related classes.
2026-03-05 Devices's online/offline status implemented on Android APP.
2026-03-26 Solved multiple Android APP warnings.
    [DialogManager.java]
2026-04-03 Fixed low responsiveness bug.
    [DialogManager.java, MainActivity.java, MainScreenRenderer.java]
2026-04-16 Button click flickering fixed.
    [DialogManager.java, MainScreenRenderer.java]
2026-04-30 Room filtering improved on Android APP.
2026-04-30 ON-OFF module wiring diagram included.
2026-05-27 Camera streaming implemented.
